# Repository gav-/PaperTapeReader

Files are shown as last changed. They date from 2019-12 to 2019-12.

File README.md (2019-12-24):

# PaperTapeReader
Punched paper tape reader - 3D model and source code.

This is a punched paper tape reader that allows tape to be pulled through by 
hand, using the tape's feed holes as a clock/trigger. The tape can be pulled 
at any speed as long as it is not allowed to slacken.

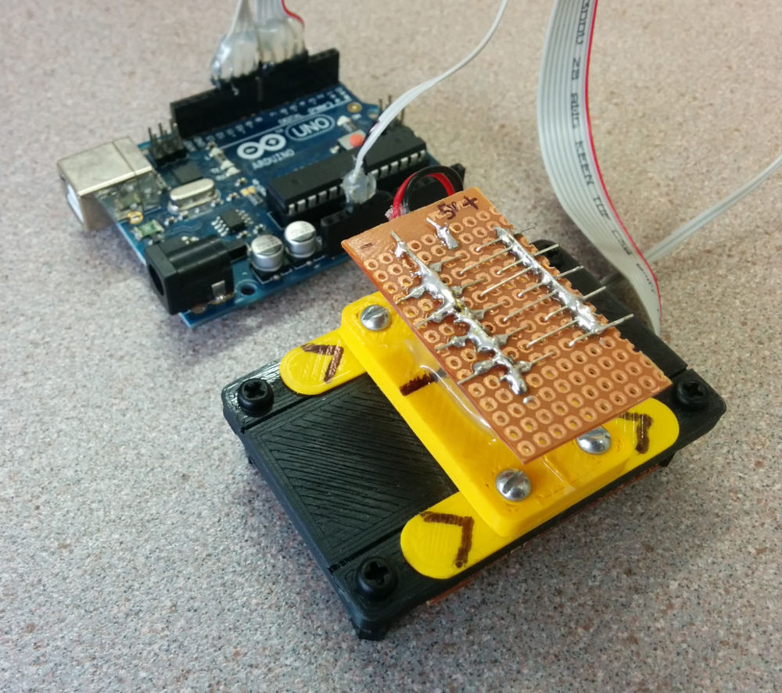
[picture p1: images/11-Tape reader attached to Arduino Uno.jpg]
Paper Tape Reader


## Notes
These are some extra notes off the top of my head:

* In the 3D model, the LED emitter hole for the paper tape feed hole is smaller than the rest. This turned out to be a mistake, and the emitter for that hole had to brightened to compensate. It is recommended to modify the "feedHoleRadius" in model/PaperTapeReader.scad to the same as "dataHoleRadius", and export a new .stl from OpenSCAD.

* Setting the correct emitter brightness is important. Ideally it is as bright as possible where the paper still satisfactorily blocks the light where no holes are punched. Test with various resistor values and your own paper tape to get it right.

* I haven't added a schematic, but the wiring should be simple, basically just power the emitters from a 5V out (and an appropriate resistor), and tie the phototransistors to pins 4,5,6,7,8,9,10,11. I used external pull-up resistors on the phototransistors, this was a waste of time as the Arduino Uno has internal pull-ups that can be enabled. The setup() function in src/TapeReader/TapeReader.ino should be changed to enable internal pull-ups.

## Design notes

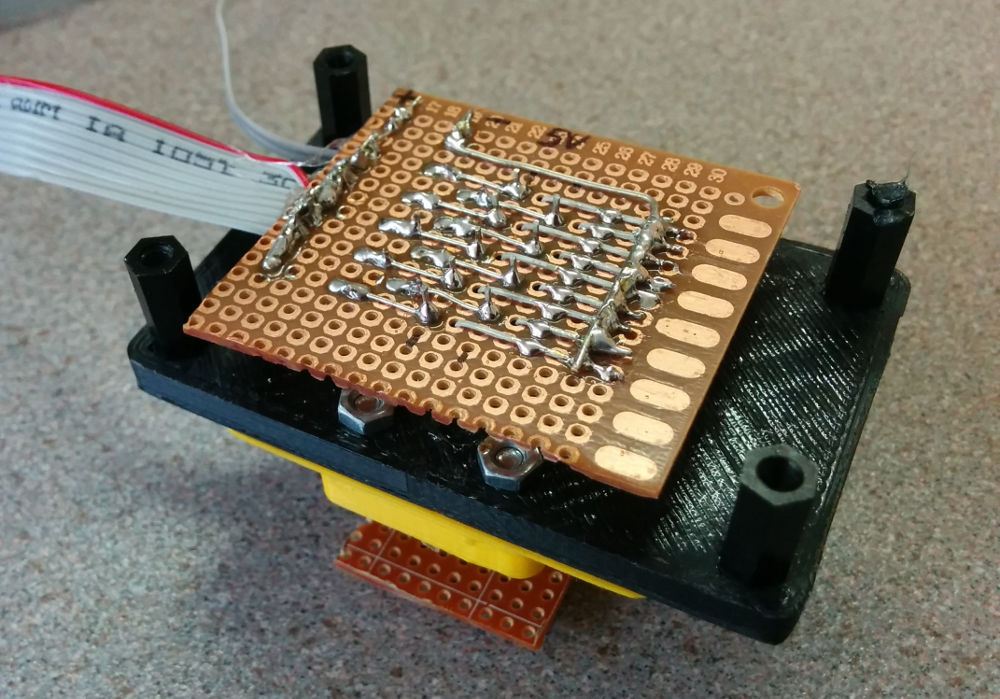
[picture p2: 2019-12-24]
images/10-Base board attached to phototransistors.jpg

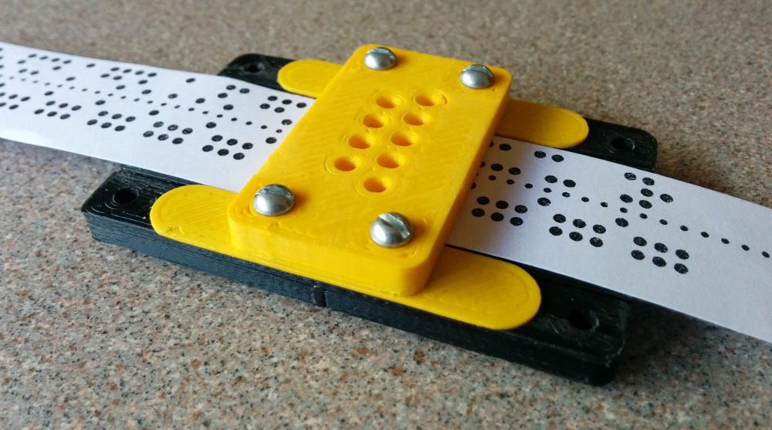
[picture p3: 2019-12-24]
images/01-Tape reader.jpg

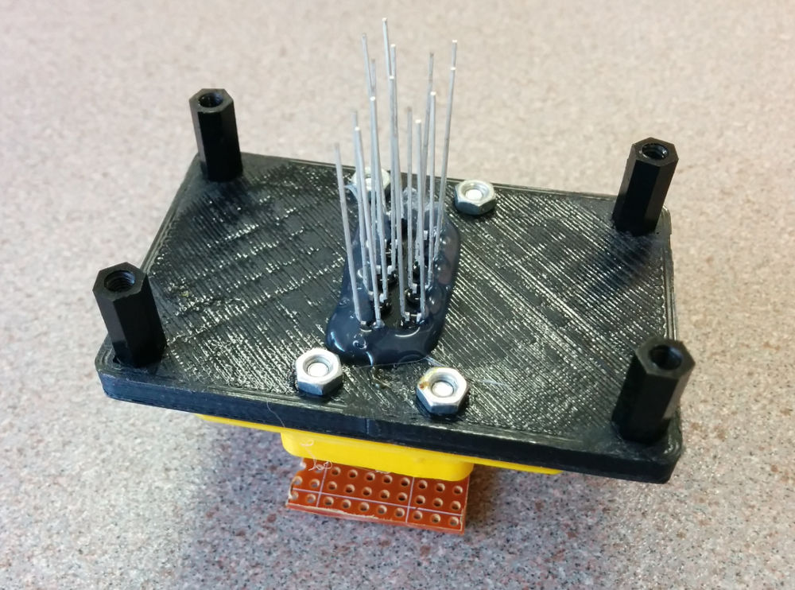
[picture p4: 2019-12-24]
images/08-Base with phototransistors.jpg

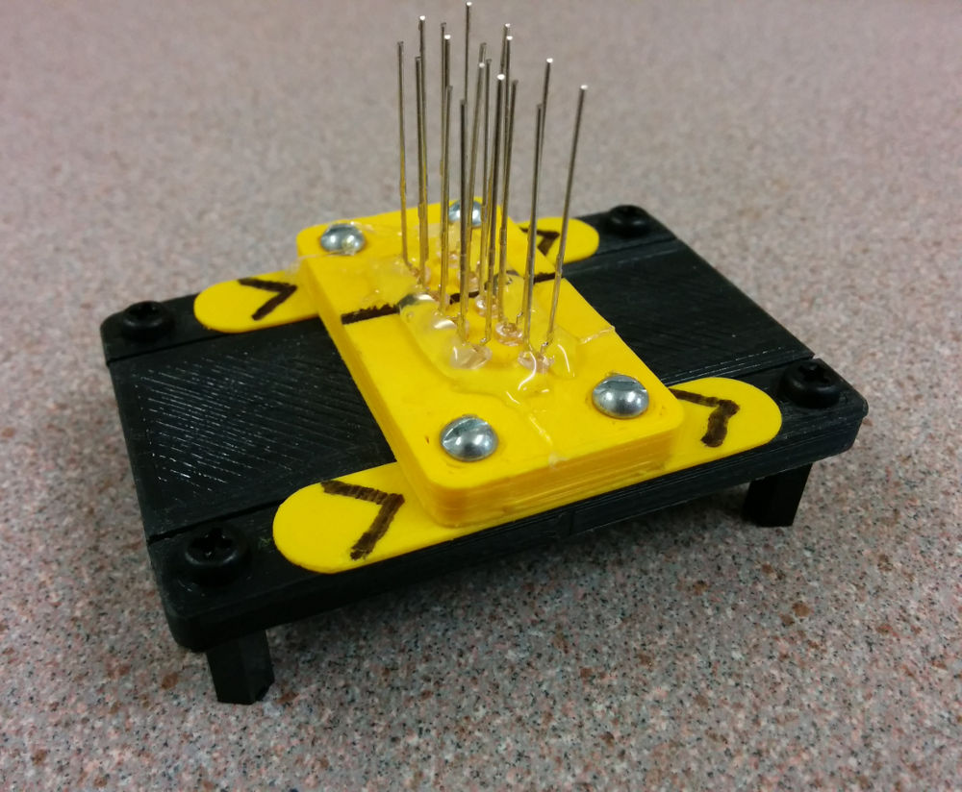
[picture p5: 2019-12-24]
images/04-Hot glued IR LEDs.jpg

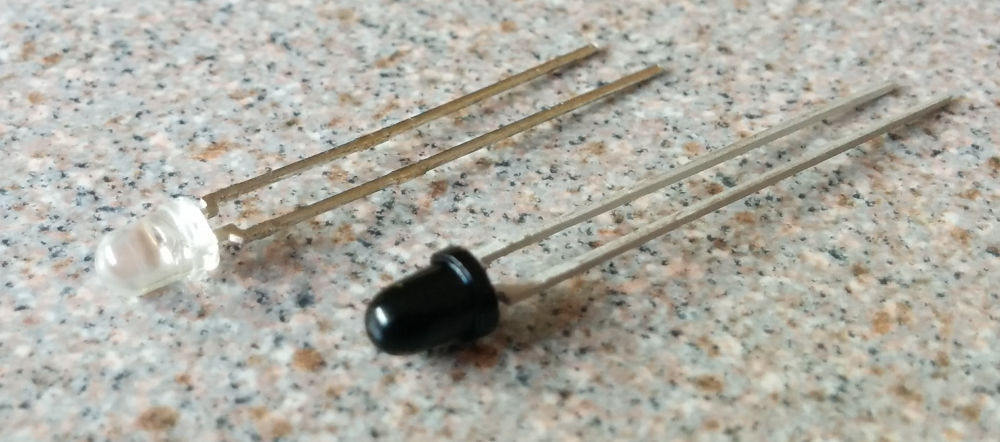
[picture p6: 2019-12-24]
images/03-IR LED and photodiode.jpg

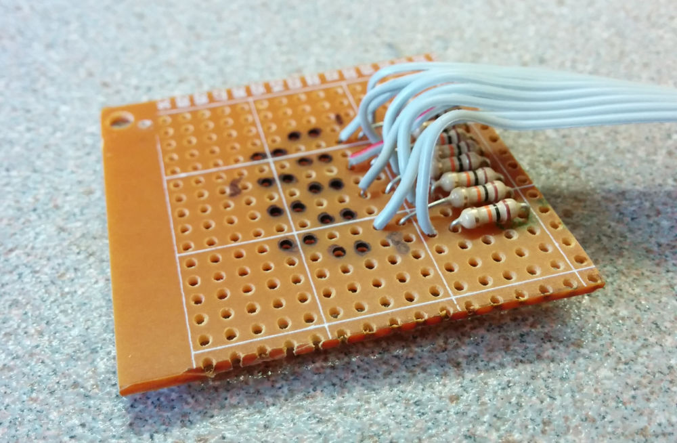
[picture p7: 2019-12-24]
images/09-Base board with 10k pull up resistors.jpg

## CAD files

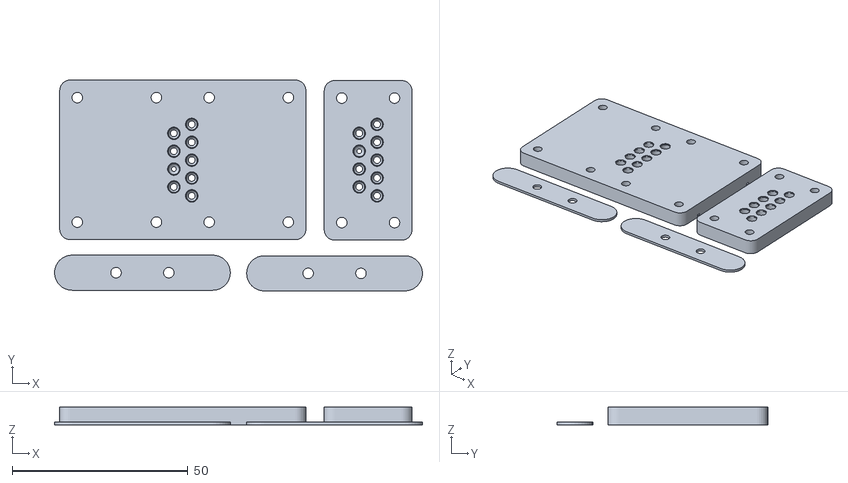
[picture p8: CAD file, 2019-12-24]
model/PaperTapeReader.print-ready.stl
104.6 x 60.0 x 5.00

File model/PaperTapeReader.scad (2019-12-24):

/**
 * 1" punched paper tape reader model.
 *
 * 20150928 - Gavin Stewart.
 */

/**
 * Tape dimension constants.
 */
tapeWidth = 25.4;				// mm (1.0")
holePitch = 2.54;				// mm (0.1")
dataHoleRadius = 1.83 / 2 + 0.05;	// mm (0.072" diameter) + 0.05 extra
feedHoleRadius = 1.17 / 2 + 0.10;	// mm (0.046" diameter) + 0.10 extra

/**
 * Reader dimesion constants.
 */
shoulderWidth = 10;
baseThickness = 4 + 1;
baseLength = 70;
gateLength = 25;
guideLength = 50;
guideThickness = 0.8;
cornerRadius = 3;				// Rounded corners on parts.
partSpacing = 2;				// There are three stacked parts.
screwHoleRadius = 3 / 2;

/**
 * Calculated constants.
 */
halfShoulderWidth = shoulderWidth / 2;
baseWidth = tapeWidth + (shoulderWidth * 2);

/**
 * Set default number of fragments for OpenSCAD curves.
 */
$fn = 32;

/**
 * Correction for differenced shapes in mm.
 * Fudge to make sure that holes/cuts/paths are big enough for screws, etc.
 */
differenceCorrection = 0.15;

/**
 * LED / phototransistor pathway.
 */
module ledPathway (length) {   
	bodyRadius = 1.5 + (differenceCorrection / 2);	
	lipRadius = 1.7 + (differenceCorrection / 2);
   height = 3.7; 		// Height of led body (after shoulder) to tip.
 
	translate([0, 0, bodyRadius]) {
		sphere(r = bodyRadius);
		cylinder(h = height - bodyRadius + 0.1, r = bodyRadius);
	   translate([0, 0, height - bodyRadius])
			cylinder(h = length, r = lipRadius);
   }
}

/**
 * Generic hole pathway with inside diameter correction.
 */
module holePathway (radius, length) {
	radiusCorrected = radius + (differenceCorrection / 2);
	cylinder(h = length, r = radius);
}

/**
 * An ledPathway() with a holePathway() in front of it.
 */
module ledPathwayAndHole (ledLength, holeRadius, holeLength) {
	ledPathway(ledLength);
	translate([0, 0, -ledLength])
 		holePathway(holeRadius, holeLength + 1);
}

/**
 * Rounded cube only on Z axis. Uses cornerRadius constant.
 */
module roundedCubeZ (size) {
	hull() {
		translate([cornerRadius, cornerRadius, 0])
			cylinder(r = cornerRadius, h = size[2]);
		translate([size[0] - cornerRadius, cornerRadius, 0])
			cylinder(r = cornerRadius, h = size[2]);
		translate([cornerRadius, size[1] - cornerRadius, 0])
			cylinder(r = cornerRadius, h = size[2]);
		translate([size[0] - cornerRadius, size[1] - cornerRadius, 0])
			cylinder(r = cornerRadius, h = size[2]);
	}
}

/**
 * Paper tape track body.
 */
module trackBody () {
	paperPathWidth = tapeWidth + differenceCorrection;
	led9X = baseLength / 2 + holePitch;
	led9Y = shoulderWidth + (differenceCorrection / 2) + holePitch;
	edgeChannelWidth = 1;

	difference() {
		// base
		roundedCubeZ([baseLength, baseWidth, baseThickness]);

		// outer edge channels of tape pathway for alignment of edge side assembly.
		translate([-0.1, shoulderWidth - edgeChannelWidth, baseThickness - edgeChannelWidth])
			cube([baseLength + 0.2, edgeChannelWidth, edgeChannelWidth + 0.1]);
		translate([-0.1, shoulderWidth + paperPathWidth, baseThickness - edgeChannelWidth])
			cube([baseLength + 0.2, edgeChannelWidth, edgeChannelWidth + 0.1]);

		// 9 LED pathways, starting at 9.
		translate([led9X - (holePitch * 0), led9Y + (holePitch * 0), baseThickness - 1]) 
			rotate([0, 180, 0]) 
				ledPathwayAndHole(baseThickness, dataHoleRadius, baseThickness);
		translate([led9X - (holePitch * 2), led9Y + (holePitch * 1), baseThickness - 1]) 
			rotate([0, 180, 0]) 
				ledPathwayAndHole(baseThickness, dataHoleRadius, baseThickness);
		translate([led9X - (holePitch * 0), led9Y + (holePitch * 2), baseThickness - 1]) 
			rotate([0, 180, 0]) 
				ledPathwayAndHole(baseThickness, dataHoleRadius, baseThickness);
		translate([led9X - (holePitch * 2), led9Y + (holePitch * 3), baseThickness - 1]) 
			rotate([0, 180, 0]) 
				ledPathwayAndHole(baseThickness, dataHoleRadius, baseThickness);
		translate([led9X - (holePitch * 0), led9Y + (holePitch * 4), baseThickness - 1]) 
			rotate([0, 180, 0]) 
				ledPathwayAndHole(baseThickness, dataHoleRadius, baseThickness);
		translate([led9X - (holePitch * 2), led9Y + (holePitch * 5), baseThickness - 1]) 
			rotate([0, 180, 0]) 
				ledPathwayAndHole(baseThickness, feedHoleRadius, baseThickness);
		translate([led9X - (holePitch * 0), led9Y + (holePitch * 6), baseThickness - 1]) 
			rotate([0, 180, 0]) 
				ledPathwayAndHole(baseThickness, dataHoleRadius, baseThickness);
		translate([led9X - (holePitch * 2), led9Y + (holePitch * 7), baseThickness - 1]) 
			rotate([0, 180, 0]) 
				ledPathwayAndHole(baseThickness, dataHoleRadius, baseThickness);
		translate([led9X - (holePitch * 0), led9Y + (holePitch * 8), baseThickness - 1]) 
			rotate([0, 180, 0]) 
				ledPathwayAndHole(baseThickness, dataHoleRadius, baseThickness);

		// Corner screw holes (for attaching rubber feet, or mounting).
		translate([halfShoulderWidth, halfShoulderWidth, -0.1])
			holePathway(screwHoleRadius, baseThickness + 0.2);
		translate([baseLength-halfShoulderWidth, halfShoulderWidth, -0.1])
			holePathway(screwHoleRadius, baseThickness + 0.2);
		translate([halfShoulderWidth, baseWidth - halfShoulderWidth, -0.1])
			holePathway(screwHoleRadius, baseThickness + 0.2);
		translate([baseLength-halfShoulderWidth, baseWidth - halfShoulderWidth, -0.1])
			holePathway(screwHoleRadius, baseThickness + 0.2);
		
	}
}

module topGate () {
	paperPathWidth = tapeWidth + differenceCorrection;
	led9X = gateLength / 2 + holePitch;
	led9Y = shoulderWidth + (differenceCorrection / 2) + holePitch;
	
	// Centre over trackBody()
	translate([(baseLength / 2) - (gateLength / 2), 0, baseThickness + guideThickness + partSpacing * 2]) {

	difference() {
		roundedCubeZ([gateLength, baseWidth, baseThickness]);

		// 9 LED pathways, starting at 9.
		translate([led9X - (holePitch * 0), led9Y + (holePitch * 0), 1]) 	
				ledPathwayAndHole(baseThickness, dataHoleRadius, baseThickness);
		translate([led9X - (holePitch * 2), led9Y + (holePitch * 1), 1]) 
				ledPathwayAndHole(baseThickness, dataHoleRadius, baseThickness);
		translate([led9X - (holePitch * 0), led9Y + (holePitch * 2), 1]) 
				ledPathwayAndHole(baseThickness, dataHoleRadius, baseThickness);
		translate([led9X - (holePitch * 2), led9Y + (holePitch * 3), 1]) 
				ledPathwayAndHole(baseThickness, dataHoleRadius, baseThickness);
		translate([led9X - (holePitch * 0), led9Y + (holePitch * 4), 1]) 
				ledPathwayAndHole(baseThickness, dataHoleRadius, baseThickness);
		translate([led9X - (holePitch * 2), led9Y + (holePitch * 5), 1])  
				ledPathwayAndHole(baseThickness, feedHoleRadius, baseThickness);
		translate([led9X - (holePitch * 0), led9Y + (holePitch * 6), 1])  
				ledPathwayAndHole(baseThickness, dataHoleRadius, baseThickness);
		translate([led9X - (holePitch * 2), led9Y + (holePitch * 7), 1]) 
				ledPathwayAndHole(baseThickness, dataHoleRadius, baseThickness);
		translate([led9X - (holePitch * 0), led9Y + (holePitch * 8), 1])  
				ledPathwayAndHole(baseThickness, dataHoleRadius, baseThickness);
	}

	}
}

module tapeGuide () {

	// Centre over trackBody()
	translate([(baseLength / 2) - (guideLength / 2), 0, baseThickness + partSpacing]) {

	// One side
	translate([0, halfShoulderWidth, 0])
		hull() {
			translate([halfShoulderWidth, 0, 0])
				cylinder(r = halfShoulderWidth, h = guideThickness);
			translate([guideLength - halfShoulderWidth, 0, 0])
				cylinder(r = halfShoulderWidth, h = guideThickness);
		}

	// Other side
	translate([0, baseWidth - halfShoulderWidth, 0])
		hull() {
			translate([halfShoulderWidth, 0, 0])
				cylinder(r = halfShoulderWidth, h = guideThickness);
			translate([guideLength - halfShoulderWidth, 0, 0])
				cylinder(r = halfShoulderWidth, h = guideThickness);
		}

	}
}


// Combine parts, and cut screw holes through them.
screwBaseX = (baseLength / 2) - (gateLength / 2);
screwBaseHoleHeight = baseThickness + baseThickness + guideThickness + partSpacing * 2 + 0.2;
difference() {
	union() {
		trackBody();
		tapeGuide();
		topGate();
	}
	// Screw holes
	translate([screwBaseX + halfShoulderWidth, halfShoulderWidth, -0.1])
		holePathway(screwHoleRadius, screwBaseHoleHeight);
	translate([screwBaseX + gateLength - halfShoulderWidth, halfShoulderWidth, -0.1])
		holePathway(screwHoleRadius, screwBaseHoleHeight);
	translate([screwBaseX + halfShoulderWidth, baseWidth - halfShoulderWidth, -0.1])
		holePathway(screwHoleRadius, screwBaseHoleHeight);
	translate([screwBaseX + gateLength - halfShoulderWidth, baseWidth - halfShoulderWidth, -0.1])
		holePathway(screwHoleRadius, screwBaseHoleHeight);
}

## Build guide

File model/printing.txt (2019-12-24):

Printing notes for Paper Tape Reader model:

- rotate base 180 degrees on x-axis (or y-axis), so that the paper path will be
  printed flat on the bed.

- use a 1mm drill bit to ream the feed holes.

- use a 1.5mm drill bit to ream the data holes.

- use a 3mm bit to ream the screw holes.

- it is possible to use a 3mm bit (with drill in reverse) to gently ream
  the LED holes.

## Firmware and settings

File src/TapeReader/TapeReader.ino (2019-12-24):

/**
 * 1" Punched Paper Tape Reader developed on Arduino UNO with 1.6.5-r5 IDE.
 * 
 * @author Gavin Stewart <gavin@stewart.com.au>
 * 20151003
 */

#define BUILDSERIAL "20151004"

/**
 * Configurable constants.
 */
const uint8_t feedInterrupt = 1;              // Pin 3 on Uno.
const uint8_t dataPins[] = { 4, 5,  6,  7,    // High nybble of Atmega 328 PORT-D (Uno PIND).
                             8, 9, 10, 11 };  // Low nybble of Atmega 328 PORT-B (Uno PINB).
HardwareSerial& useSerial = Serial;           // Serial port we are using, e.g. Serial on Uno, Serial1 on Mega.
const uint32_t serialSpeed = 115200;          // 115200 appears good enough to avoid input data overflow.

// How we read a byte from input registers (Atmega PORTs).
// Note that low value is a hole (1), and high value is no hole (0), so we complement/invert the result (~).
#define READBYTE() ~(((PIND & 0xf0) >> 4) | ((PINB & 0x0f) << 4))  

/**
 * Non-configurable constants and globals.
 */
const uint8_t dataPinsSize = sizeof(dataPins) / sizeof(dataPins[0]);  // Length of dataPins[] array.

volatile uint8_t data;                        // Byte as read by feedSenseISR().
volatile bool dataAvailable;                  // Set by feedSenseISR() when new data available, must be cleared when read.
volatile bool dataOverflow;                   // Set by feedSenseISR() if dataAvailable is still set on next interrupt.

enum State {
  STATE_IDLE,
  STATE_DUMP,
  STATE_INTERRUPT,
};

uint8_t state;              // Current state.

enum Dump {
  DUMP_NONE,
  DUMP_HEX,
  DUMP_TAPE,
};

uint8_t dump;               // Current dump type.
uint8_t dumpColumns;        // Number of columns we have dumped to terminal so far (for wrapping).
uint32_t dumpAddress;       // Line number for hex dumps. 32bit - would like to see 4GB tape!

uint8_t dataFIFO[3];        // FIFO queue to combine two sensor columns at different data ingestion times.
bool dataSkipNulls;         // Set at start of dump, then unset on first non-null byte received.

/**
 * Banner and help menu.
 */
void printHelp () {
  useSerial.print(F(
    "\n"
    "+----------------------------------------+\n"
    "|      1\" Punched Tape Reader            |\n"
    "|          Build: " BUILDSERIAL "               |\n"
    "|                                        |\n"
    "|  Copyright (C) 2015                    |\n"
    "|  Gavin Stewart <gavin@stewart.com.au>  |\n"
    "+----------------------------------------+\n"
    "\n"
  ));

  useSerial.print(F(
    " ?  - This help.\n"
    " h  - Hexdump format. Use \"xxd -r\" to convert to binary.\n"
    " s  - Show current holes under head (debug).\n"
    " t  - Tape-like output with hex, decimal, octal, ASCII.\n"
    " <any key> - Interrupt the current dump.\n"
    "\n"
  ));
  
  printPrompt();
}

/**
 * Input prompt.
 */
void printPrompt () {
  useSerial.print(F("> "));
}

/**
 * Arduino required setup function.
 */
void setup () {
  // Use a fast enough speed, too slow increases chance of input data overflow.
  useSerial.begin(serialSpeed);

  // Initialise data input pins. We have external pull-up resistors, so they
  // are not enabled here.
  for (uint8_t i = 0; i < dataPinsSize; i++) {
    pinMode(dataPins[i], INPUT);
  }
  
  printHelp();

  // Initial state.
  state = STATE_IDLE;
  dump = DUMP_NONE;
}

/** 
 * Feed hole sense Interrupt Service Routine. 
 * 
 * Called each time the feed hole sensor triggers a falling edge (a hole appears).
 * The eight data sensor values are read into a byte.
 */
void feedSenseISR () {
  // Detect data overflow condition.
  if (dataAvailable) {
    dataOverflow = true;
  }

  // Read a byte and set the notification flag.
  data = READBYTE();
  dataAvailable = true;
}

/**
 * Data dump initialisation routine.
 * 
 * @param uint8_t dumpType
 *  See Dump enum.
 */
void dumpInit (uint8_t dumpType) {
  useSerial.println(F("+ Dump started."));
  state = STATE_DUMP;
  dump = dumpType;
  dumpColumns = 0;
  dumpAddress = 0;
  dataAvailable = false;
  dataOverflow = false;
  dataFIFO[0] = 0;
  dataFIFO[1] = 0;
  dataFIFO[2] = 0;
  dataSkipNulls = true;
  attachInterrupt(feedInterrupt, feedSenseISR, FALLING);
}

/**
 * Data dump cleanup routine.
 */
void dumpStop () {
  detachInterrupt(feedInterrupt);
  state = STATE_IDLE;
  dump = DUMP_NONE;
  dataAvailable = false;
  dataOverflow = false;
  useSerial.println(F("\n+ Dump stopped."));
  printPrompt();
}

/**
 * Dump the provided val to serial port in the configured dump format.
 * 
 * @param uint8_t val
 *  Value to dump to serial port.
 */
void dumpData (uint8_t val) {
  char buff[26];      // Note this maximum output buffer size including terminating null!
  uint8_t pos = 0;    // Cursor position in buffer.
  const char hex[] = "0123456789abcdef";  // Hex translation string.
  #define MAXDUMPCOLUMNS 16               // Number of output columns
  
  static char asciiBuff[MAXDUMPCOLUMNS + 3 + 2];    // Persistent buffer for hexdump ascii field,
                                                    // space, 2x'|' borders, newline and null.
  static char asciiBuffPos;                         // Persistent position in hexdump ascii buffer.

  //Serial.print("Address:");
  //Serial.println(dumpAddress, HEX);
  
  switch (dump) {
         
    case DUMP_HEX:
      // Check for start of new line.
      if (!(dumpAddress % MAXDUMPCOLUMNS)) {
        // Build up 32-bit address field in hex.
        buff[pos++] = hex[(dumpAddress >> 28) & 0xf];
        buff[pos++] = hex[(dumpAddress >> 24) & 0xf];
        buff[pos++] = hex[(dumpAddress >> 20) & 0xf];
        buff[pos++] = hex[(dumpAddress >> 16) & 0xf];
        buff[pos++] = hex[(dumpAddress >> 12) & 0xf];
        buff[pos++] = hex[(dumpAddress >>  8) & 0xf];
        buff[pos++] = hex[(dumpAddress >>  4) & 0xf];
        buff[pos++] = hex[(dumpAddress >>  0) & 0xf];
        buff[pos++] = ' ';
        buff[pos++] = ' ';

        // Reset ascii buffer.
        asciiBuffPos = 0;        
        asciiBuff[asciiBuffPos++] = ' ';             
        asciiBuff[asciiBuffPos++] = '|';
      }

      // Dump byte in hex.
      buff[pos++] = hex[val >> 4];
      buff[pos++] = hex[val & 0x0f];
      buff[pos++] = ' ';
      dumpColumns++;

      // Store ASCII.
      asciiBuff[asciiBuffPos++] = (val >= 33 && val <= 126) ? val : '.';
      
      break;
      
    case DUMP_TAPE:    
      // Tape edge. (1)
      buff[pos++] = '|';
      
      // First three holes (LSb first) (4)
      for (uint8_t i = 0; i < 3; i++) {
        if (val & (1 << i)) {
          buff[pos++] =  'o';
        } else {
          buff[pos++] = ' ';
        }
      }
      
      // Feed hole (5)
      buff[pos++] = '.';
      
      // Last five holes (MSb last) (10)
      for (uint8_t i = 3; i < 8; i++) {
        if (val & (1 << i)) {
          buff[pos++] =  'o';
        } else {
          buff[pos++] = ' ';
        }
      }

      // Tape edge. (11)
      buff[pos++] = '|';

      // Hex. (14)
      buff[pos++] = ' ';
      buff[pos++] = hex[val >> 4];
      buff[pos++] = hex[val & 0x0f];

      // Decimal. (18)
      buff[pos++] = ' ';
      buff[pos++] = (val / 100) + '0';
      buff[pos++] = (val % 100 / 10) + '0';
      buff[pos++] = (val % 10) + '0';

      // Octal. (22)
      buff[pos++] = ' ';
      buff[pos++] = ((val >> 6) & 7) + '0';
      buff[pos++] = ((val >> 3) & 7) + '0';
      buff[pos++] = ((val >> 0) & 7) + '0';
      
      // ASCII. (24)
      buff[pos++] = ' ';
      buff[pos++] = (val >= 33 && val <= 126) ? val : '.';

      // Newline. (25)
      buff[pos++] = '\n';
      
      break;
  }

  // String terminator at last position.
  buff[pos] = '\0';

  // Output dump data buffer.
  useSerial.print(buff);

  // After MAXDUMPCOLUMNS data columns, output hexdump ascii field with a newline.
  if (dumpColumns >= MAXDUMPCOLUMNS) {
    asciiBuff[asciiBuffPos++] = '|';
    asciiBuff[asciiBuffPos++] = '\n';
    asciiBuff[asciiBuffPos] = '\0';   // ascii field string terminator.
    useSerial.print(asciiBuff);
    dumpColumns = 0;      // Reset, will be starting on a new line.
  }

  // Increment dump address.
  dumpAddress++;
}

/**
 * Read character from serial port and handle it.
 */
void handleInput () {
  char inp = useSerial.read();

  // Any key stops a dump.
  if (state == STATE_DUMP) {
    dumpStop();  
    return;
  }

  useSerial.println(inp);       // Echo input.

  uint8_t underHead;            // For 'd' - showing representation of holes under read head.
  switch(inp) {
    case 'h':
      dumpInit(DUMP_HEX);
      break;
    case 's':
      dump = DUMP_TAPE;
      underHead = READBYTE();
      dumpData(underHead & B10101101); // Column 2 sensor data.
      dumpData(0);                     // Column with no sensors.
      dumpData(underHead & B01010010); // Column 1 sensor data.
      dump = DUMP_NONE;
      printPrompt();
      break;
    case 't':
      dumpInit(DUMP_TAPE);
      break;
    case '?':
    default:      
      printHelp();
      break;
  }
}

/**
 * Arduino required loop function.
 */
void loop () {

  // Check for overflow condition.
  if (dataOverflow) { 
    dumpStop();
    useSerial.println(F("** Error: input data overflow detected."));
  }

  // Check for new data available.
  if (dataAvailable) {
    
    // Disable interrupts, copy new data, reenable interrupts ASAP.
    noInterrupts();
    uint8_t val = data;       // Make a copy of the new data.
    dataAvailable = false;    // Unset dataAvailable flag for feedSenseISR().
    interrupts();

    // Push data through FIFO (used for combining read head sensor columns).
    dataFIFO[2] = dataFIFO[1];
    dataFIFO[1] = dataFIFO[0];
    dataFIFO[0] = val;

    // Combine sensor column data:
    //
    // Column 1 (C1) has the feed sensor (S) and bits: 1, 4, 6 
    // Column 2 (C2) has the remaining bits:           0, 2, 3, 5, 7
    //
    // C1  C2
    // ------
    //     0
    //  1
    //     2      ----------------->
    //  S           tape direction
    //     3      ----------------->
    //  4
    //     5
    //  6
    //     7
    // ------
    //
    // As tape moves from left to right, an entire byte is not available until the row of holes has
    // passed both C1 and C2 sensor columns. The bits read from the row of holes under C2 "now" must be 
    // combined with the bits read from the row of holes under C1 two "feed clocks" ago.
    //
    // Note: Tape holes are least significant bit (LSb) at top, and most significant bit (MSb) at bottom.
    //       Bitmasks used below are naturally read MSb left to LSb right.
    //
    //    (  C1 from 2 clocks ago ) | (      C2 from now      )
    val = (dataFIFO[2] & B01010010) | (dataFIFO[0] & B10101101);

    if (dataSkipNulls && val == 0) {
      // We don't want to know about nulls at the beginnig of a tape dump.
    } else {
      dataSkipNulls = false;    // From now on all nulls must be dumped.
      dumpData(val);
    }
  }

  // Check for serial port input.
  if (useSerial.available()) {
    handleInput();
  }
  
}
